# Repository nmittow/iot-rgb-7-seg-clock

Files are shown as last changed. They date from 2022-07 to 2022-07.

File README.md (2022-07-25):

# iot-rgb-7-seg-clock

RGB leds arranged to simulate the look of a 7 segment display.

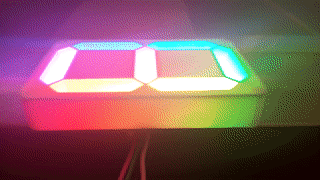
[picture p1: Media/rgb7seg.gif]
single digit rgb cycling

basic animation running on clock

Raspberry Pi &amp; ESP32 based controllers.
Raspberry Pi controller
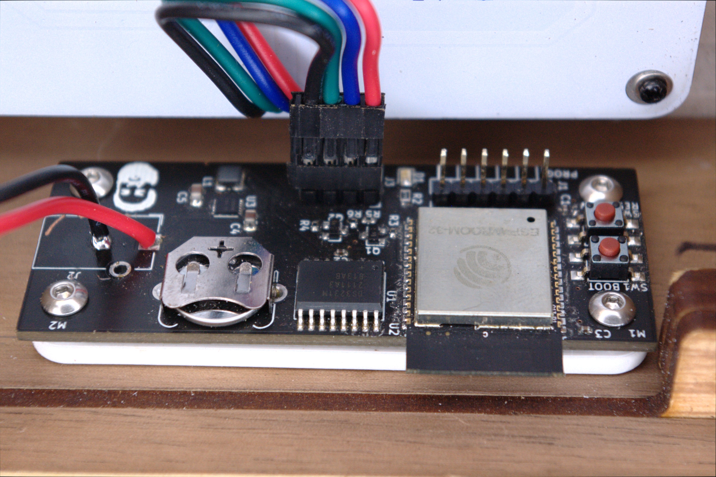
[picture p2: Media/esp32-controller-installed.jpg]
ESP32 controller


ESP32 version features: realtime clock, syncs to a network time server,  supports various time display animations.

All PCBs in KiCAD.

Raspberry Pi version features: all ESP32 features plus: 3.5mm audio jack and 5V relay controlled power output (for alarm audio), python library for controlling display &amp; alarm functionality (in-progress).

Motivation: I wanted an alarm that syncs with my various calendars (google, protonmail, etc) capable of 'smart' functionality like adjusting alarm time based on calendar events &amp; traffic conditions, etc., but wanted those calculations to happen locally (i.e. not google now/similar).  Love the look of 7 segment displays but wanted a bit more control of the display.

Construction: PCBs for controllers (ESP32 based &amp; Raspberry Pi cape), 7 segment digits are custom PCBs with APA102 addressable LEDs (3 per segment), daisy-chain-able.  3D Printed shrouds &amp; laser cut acrylic diffuser front, all in a stylish wooden box.  PCBs designed in KiCAD, 3D Modeling in AutoCAD & Fusion360.

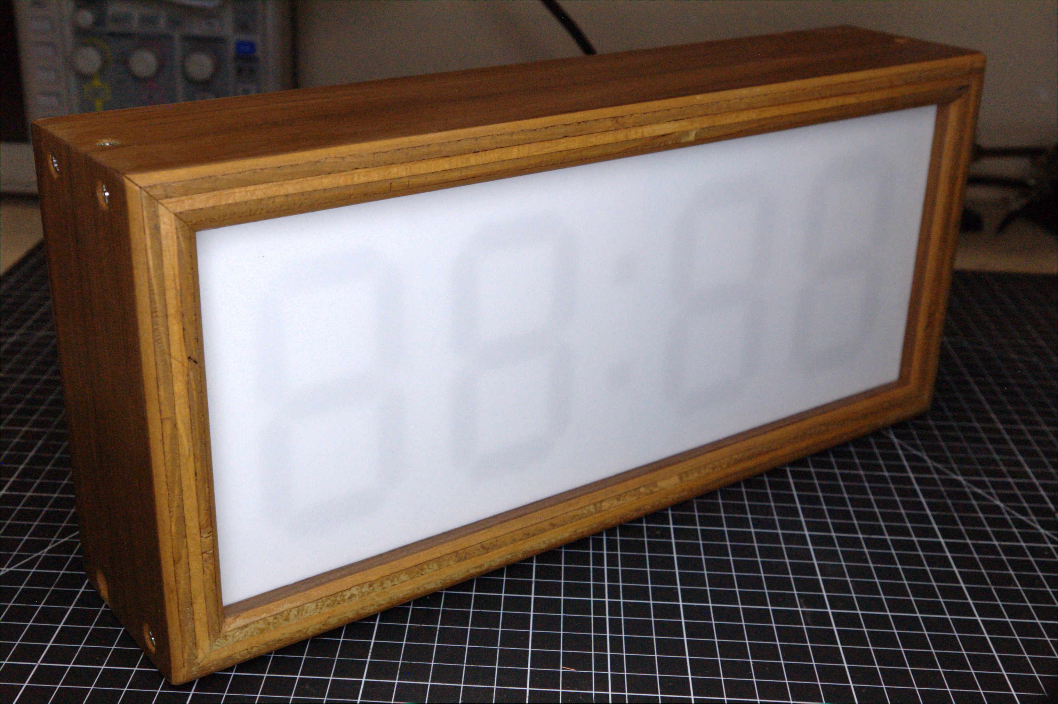
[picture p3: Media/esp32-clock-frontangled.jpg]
Front turned off

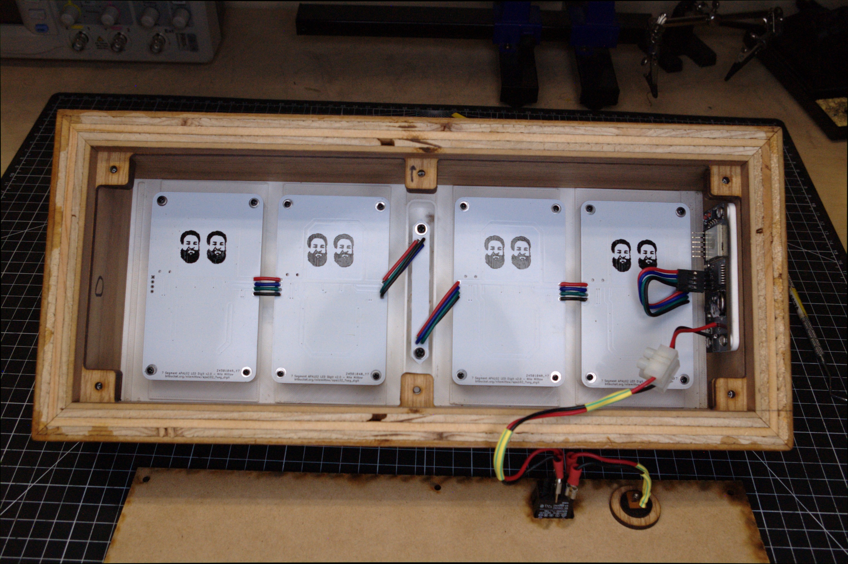
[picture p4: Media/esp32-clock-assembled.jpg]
Assembly of clock


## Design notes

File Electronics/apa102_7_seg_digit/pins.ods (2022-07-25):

hc165 | hc595 | Other | rpi gpio | Rpi Pin | Function
Qh |  |  | GPIO 9 | 21 | MISO
CLK |  |  | GPIO 11 | 23 | SCLK
CLK INH |  |  | GPIO 8 | 24 | CS0
SH/LD |  |  | GPIO 25 | 22 | en/dis loading
 | SER |  | GPIO 10 | 19 | MOSI
 | OE | GND |  |  | Output Ena
 | SRCLR | 5V |  |  | Sync. Clear
 | SRCLK |  | GPIO 7 |  | CS1

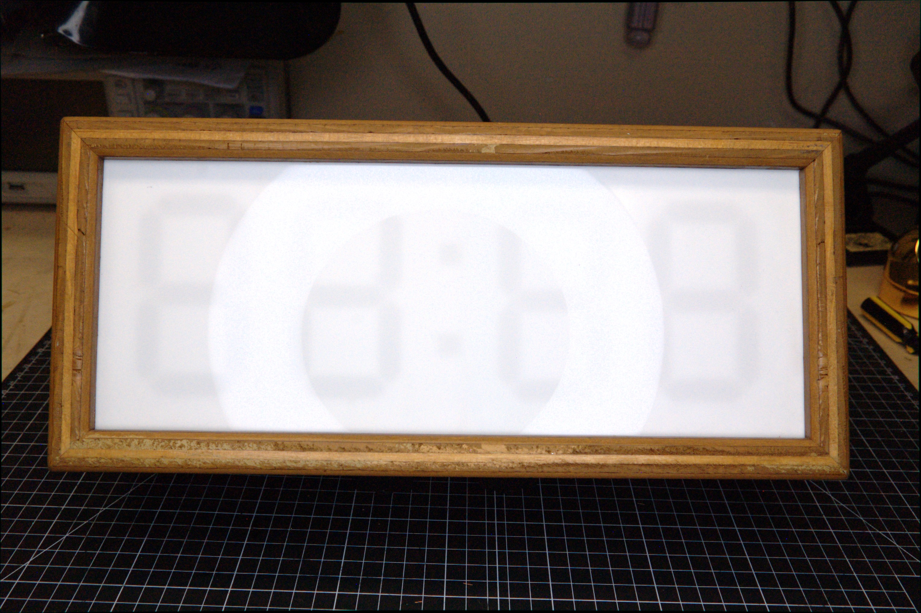
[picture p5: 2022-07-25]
Media/esp32-clock-frontflat.jpg

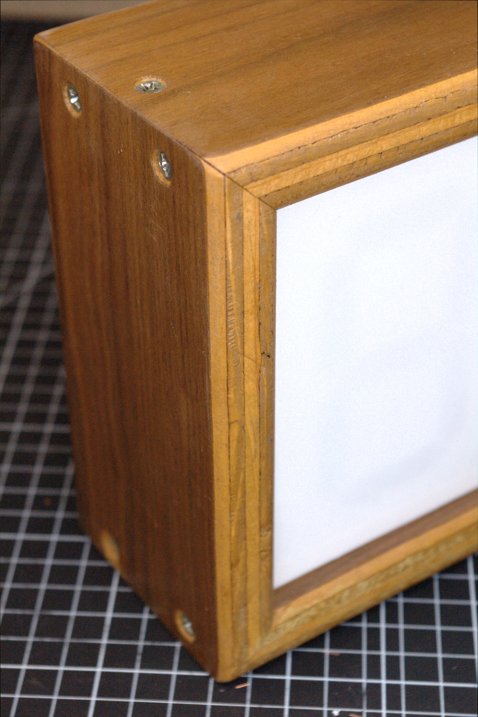
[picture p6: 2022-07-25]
Media/esp32-clock-cornercloseup.jpg

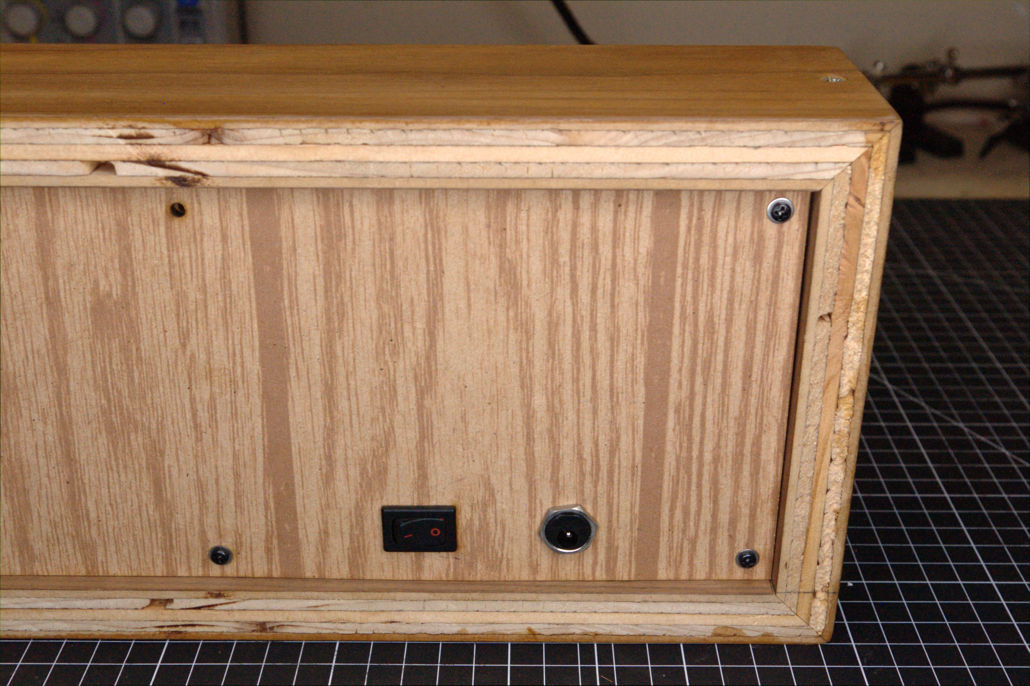
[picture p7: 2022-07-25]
Media/esp32-clock-backports.jpg

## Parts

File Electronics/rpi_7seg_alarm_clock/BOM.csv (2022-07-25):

Mouser # | Link | Mfr. # | Manufacturer | Description | RoHS | Lifecycle | Order Qty. | Price (USD) | Ext.: (USD)
655-RT314F03 | https://www.mouser.com/ProductDetail/655-RT314F03 | RT314F03 | TE Connectivity | General Purpose Relays SPDT 16A 3VDC PCB MINIATURE RELAY |  |  | 1 | $6.79 | $6.79
833-2SK3018-TP | https://www.mouser.com/ProductDetail/833-2SK3018-TP | 2SK3018-TP | Micro Commercial Components (MCC) | MOSFET N-Channel MOSFET | RoHS Compliant |  | 2 | $0.34 | $0.68
595-CD4078BPWR | https://www.mouser.com/ProductDetail/595-CD4078BPWR | CD4078BPWR | Texas Instruments | Logic Gates CMOS 8-Input NOR/OR | RoHS Compliant |  | 1 | $0.55 | $0.55
595-SN74HC08D | https://www.mouser.com/ProductDetail/595-SN74HC08D | SN74HC08D | Texas Instruments | Logic Gates Quad 2-Input | RoHS Compliant |  | 1 | $0.47 | $0.47
534-3001 | https://www.mouser.com/ProductDetail/534-3001 | 3001 | Keystone Electronics | Coin Cell Battery Holders TH COIN CELL BATTERY HOLDER 12mm | RoHS Compliant |  | 1 | $0.43 | $0.43
538-67643-2910 | https://www.mouser.com/ProductDetail/538-67643-2910 | 67643-2910 | Molex | USB Connectors USB REC 4P RA SHLD TYPE A AUFL | RoHS Compliant |  | 1 | $1.56 | $1.56
512-BSS138 | https://www.mouser.com/ProductDetail/512-BSS138 | BSS138 | ON Semiconductor | MOSFET SOT-23 N-CH LOGIC | RoHS Compliant |  | 2 | $0.26 | $0.52
771-74HC14D-T | https://www.mouser.com/ProductDetail/771-74HC14D-T | 74HC14D,653 | Nexperia | Inverters HEX INVERTER SCHMITT TRIGGER | RoHS Compliant |  | 1 | $0.46 | $0.46
700-DS3231M+ | https://www.mouser.com/ProductDetail/700-DS3231M+ | DS3231M+ | Maxim Integrated | Real Time Clock +/-5ppm, I C Real-Time Clock | RoHS Compliant |  | 1 | $7.75 | $7.75
595-SN74HC165PWR | https://www.mouser.com/ProductDetail/595-SN74HC165PWR | SN74HC165PWR | Texas Instruments | Counter Shift Registers 8-Bit Parallel-Load | RoHS Compliant |  | 1 | $0.47 | $0.47
485-4079 | https://www.mouser.com/ProductDetail/485-4079 | 4079 | Adafruit | Adafruit Accessories 2x20 Socket Riser Header for Raspberry Pi HATs and Bonnets |  | New Product | 1 | $1.95 | $1.95
603-RC0402FR-7W10KL | https://www.mouser.com/ProductDetail/603-RC0402FR-7W10KL | RC0402FR-7W10KL | Yageo | Thick Film Resistors - SMD 10K ohm 1% 50V General Purpose | RoHS Compliant By Exemption |  | 20 | $0.02 | $0.36
81-GRM155C71H104JE9D | https://www.mouser.com/ProductDetail/81-GRM155C71H104JE9D | GRM155C71H104JE19D | Murata | Multilayer Ceramic Capacitors MLCC - SMD/SMT | RoHS Compliant |  | 12 | $0.08 | $0.91

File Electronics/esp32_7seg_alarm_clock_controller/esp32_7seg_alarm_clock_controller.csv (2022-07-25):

 | Source: | /home/usb/Disks/hecate/Projects/esp32_7seg_alarm_clock_controller/esp32_7seg_alarm_clock_controller.sch
 | Date: | Sun 26 Dec 2021 02:06:49 PM PST
 | Tool: | Eeschema 5.1.12-1.fc33
 | Component Count: | 24
have? | Ref | Value | Footprint | Datasheet | Manufacturer | Vendor
yes | BT1 | CR1220 | Battery:BatteryHolder_Keystone_3001_1x12mm | ~
yes | C1 | 0.1uF | Capacitor_SMD:C_0402_1005Metric | ~
yes | C2 | 0.1uF | Capacitor_SMD:C_0402_1005Metric | ~
yes | C3 | 0.1uF | Capacitor_SMD:C_0402_1005Metric | ~
yes | C4 | CP1in 4.7uF | Capacitor_SMD:C_0805_2012Metric | ~
yes | C5 | CP1out 10uF | Capacitor_SMD:C_0805_2012Metric | ~
yes | D1 | SLED | LED_SMD:LED_0805_2012Metric | ~
 | J1 | PROG | Connector_PinHeader_2.54mm:PinHeader_1x06_P2.54mm_Horizontal | ~
yes | J2 | 5V_IN | Connector_BarrelJack:BarrelJack_CUI_PJ-102AH_Horizontal | ~
 | J3 | DISP | Connector_PinSocket_2.54mm:PinSocket_1x04_P2.54mm_Horizontal | ~
yes | L1 | LP1 4.7uH | Inductor_SMD:L_Wuerth_MAPI-3015 | ~
 | Q1 | BSS138 | Package_TO_SOT_SMD:SOT-23 | https://www.onsemi.com/pub/Collateral/BSS138-D.PDF
 | Q2 | BSS138 | Package_TO_SOT_SMD:SOT-23 | https://www.onsemi.com/pub/Collateral/BSS138-D.PDF
yes | R1 | 10K | Resistor_SMD:R_0402_1005Metric | ~
yes | R2 | RSLED_60 | Resistor_SMD:R_0603_1608Metric | ~
yes | R3 | 10K | Resistor_SMD:R_0402_1005Metric | ~
yes | R4 | 10K | Resistor_SMD:R_0402_1005Metric | ~
yes | R5 | 10K | Resistor_SMD:R_0402_1005Metric | ~
yes | R6 | 10K | Resistor_SMD:R_0402_1005Metric | ~
yes | SW1 | BOOT | Button_Switch_SMD:SW_SPST_TL3305A | ~
yes | SW2 | RESET_SW | Button_Switch_SMD:SW_SPST_TL3305A | ~
yes | U1 | DS3231M | Package_SO:SOIC-16W_7.5x10.3mm_P1.27mm | http://datasheets.maximintegrated.com/en/ds/DS3231.pdf
yes | U2 | ESP32-WROOM-32 | RF_Module:ESP32-WROOM-32 | https://www.espressif.com/sites/default/files/documentation/esp32-wroom-32_datasheet_en.pdf
yes | U3 | PAM2306AYPKE | Package_DFN_QFN:WDFN-12-1EP_3x3mm_P0.45mm_EP1.7x2.5mm | https://www.diodes.com/assets/Datasheets/PAM2306.pdf

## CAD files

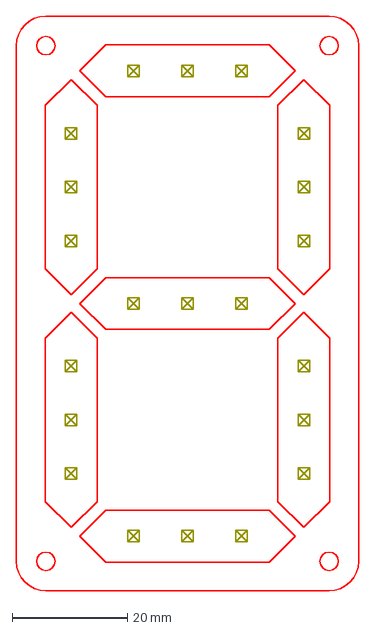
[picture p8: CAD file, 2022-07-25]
Electronics/apa102_7_seg_digit/APA102-7Seg-PCB-Template-forkicad.dxf
59.3 x 99.6 mm

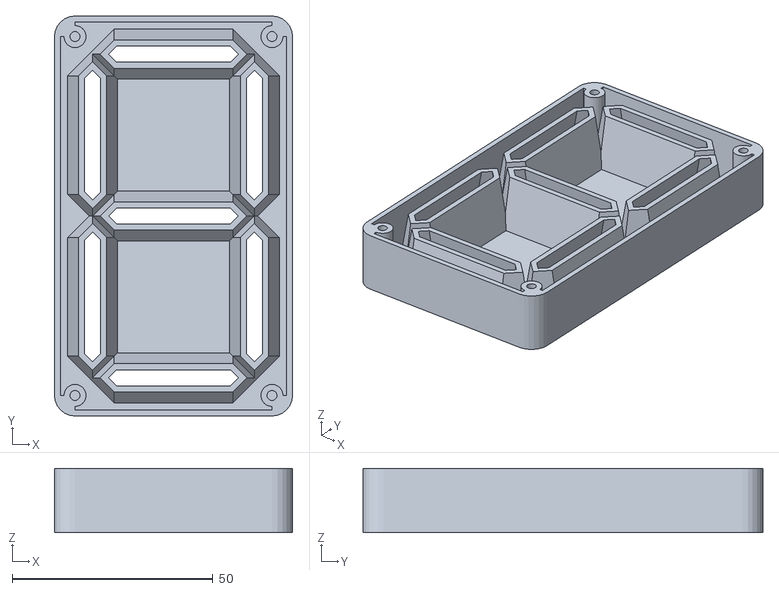
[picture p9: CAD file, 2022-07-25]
Mechanical/APA102-7Seg-PCB-Shroud.stl
59.3 x 99.6 x 16.0

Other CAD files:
Electronics/apa102_7_seg_digit/APA102-7Seg-PCB-Template.dwg
Mechanical/APA102-7Seg-PCB-Template.dwg
Electronics/apa102_7_seg_digit/APA102-7Seg-PCB-Template-forkicad.dwg
Mechanical/APA102-7Seg-PCB-Shroud.dwg
Mechanical/APA102-7Seg-PCB-Template-forkicad.dwg

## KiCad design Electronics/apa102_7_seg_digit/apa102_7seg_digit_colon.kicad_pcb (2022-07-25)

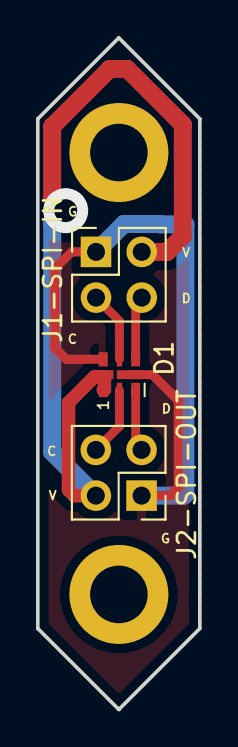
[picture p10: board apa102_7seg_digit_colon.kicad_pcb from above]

Board: 2 copper layers, 9.0 x 37.3 mm, 3 parts (0 on the bottom side), 6 nets.

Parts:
D1: A_0; LED-APA102-2020
J1-SPI-IN: SPI_IN; PinHeader_2x02_P2.54mm_Vertical
J2-SPI-OUT: SPI_OUT; PinHeader_2x02_P2.54mm_Vertical

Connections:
+5V: D1.1, J1-SPI-IN.2, J2-SPI-OUT.2
GND: D1.6, J1-SPI-IN.1, J2-SPI-OUT.1
unnamed: D1.2, J2-SPI-OUT.4
unnamed: D1.3, J2-SPI-OUT.3
unnamed: D1.4, J1-SPI-IN.4
unnamed: D1.5, J1-SPI-IN.3

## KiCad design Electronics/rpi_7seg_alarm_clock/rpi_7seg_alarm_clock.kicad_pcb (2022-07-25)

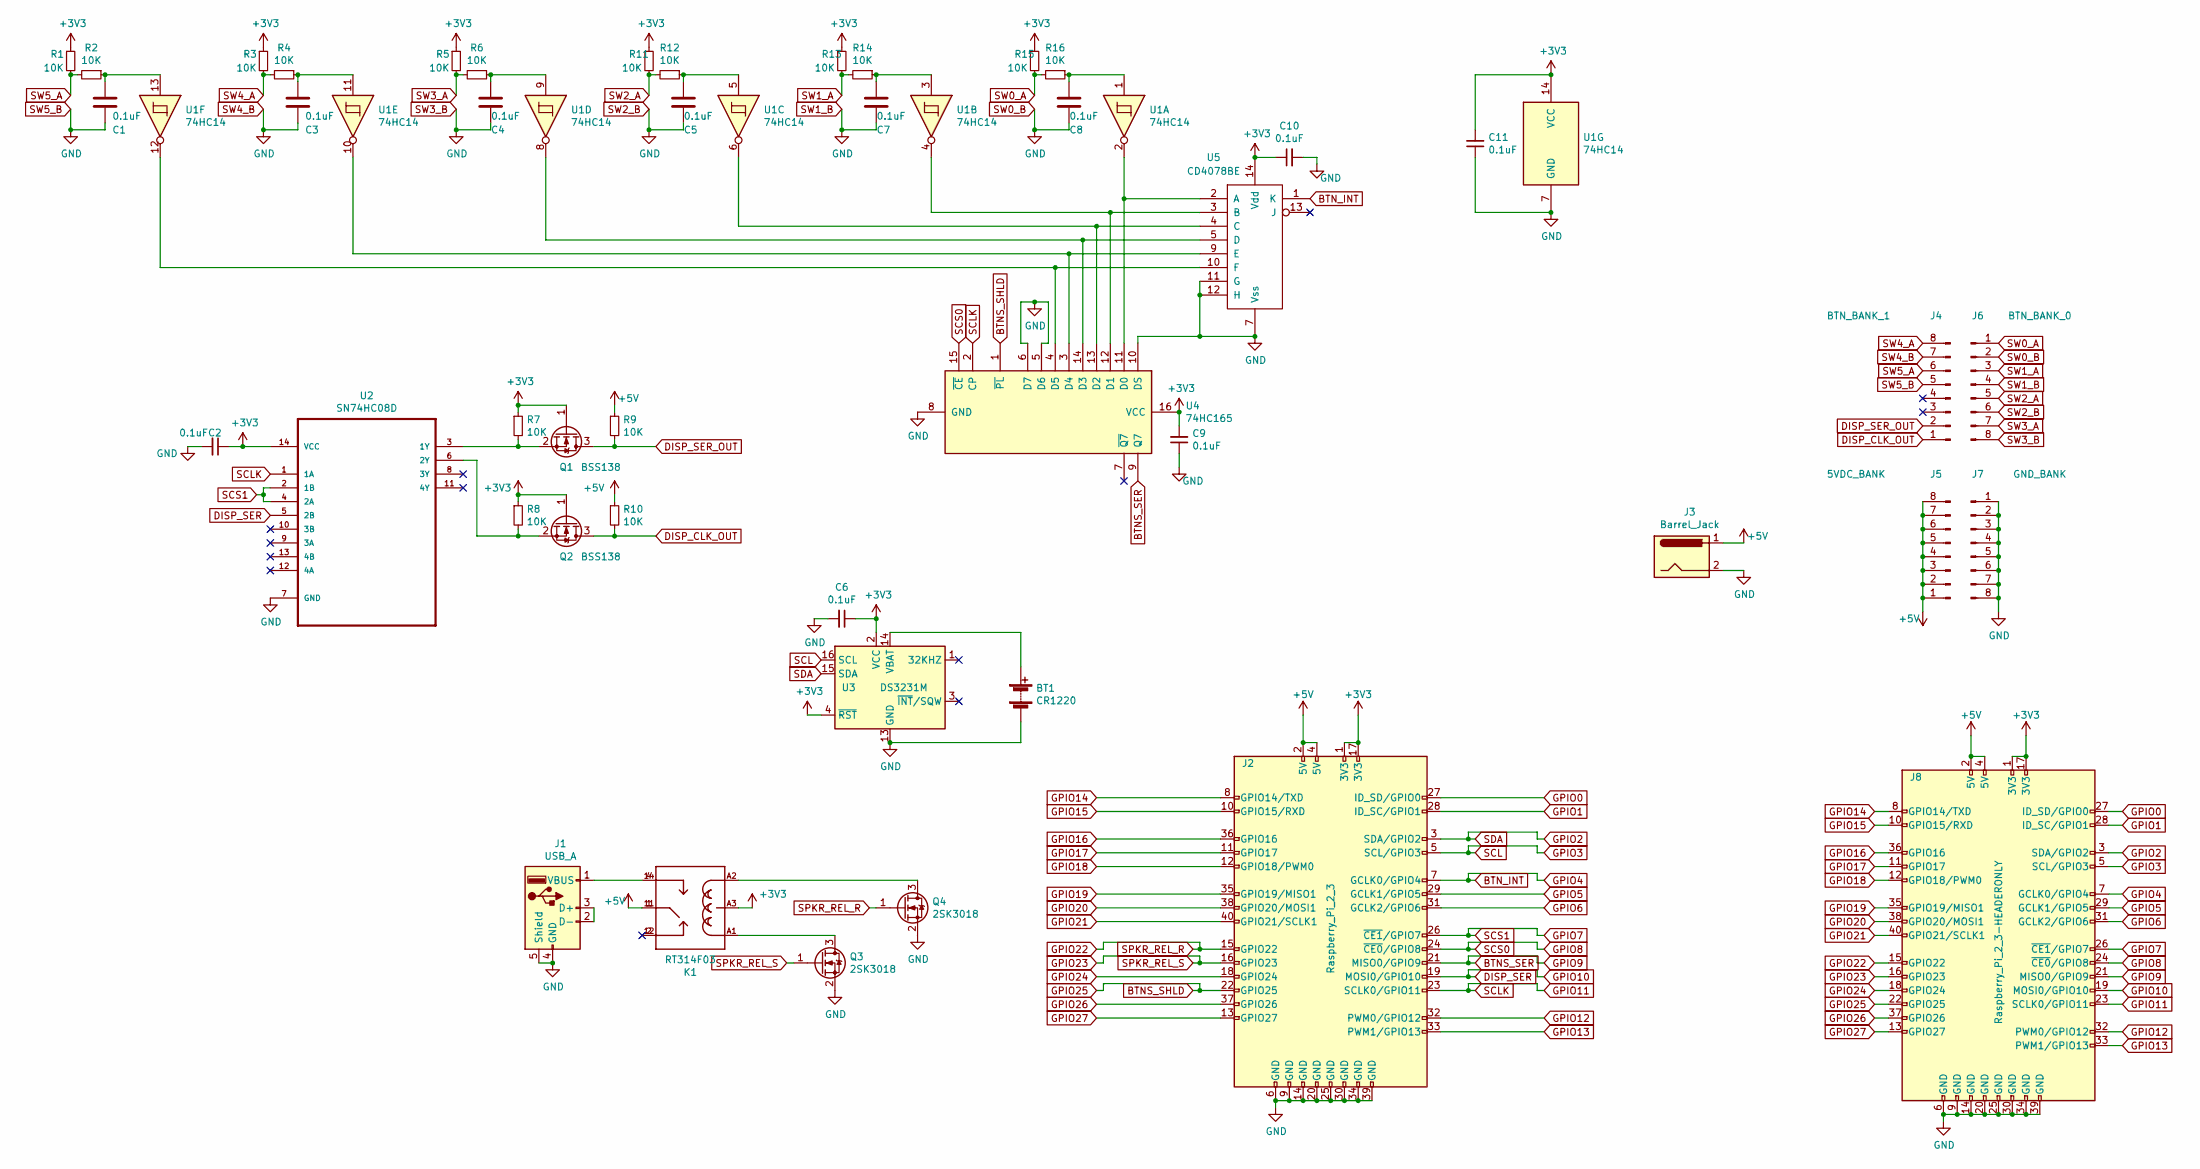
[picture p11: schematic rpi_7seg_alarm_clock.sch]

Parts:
BT1: CR1220; BatteryHolder_Keystone_3001_1x12mm
C1, C2, C3, C4, C5, C6, C7, C8, C9, C10, C11: 0.1uF; C_0805_2012Metric
J1: USB_A; USB_A_Molex_67643_Horizontal
J2: Raspberry_Pi_2_3; PinHeader_2x20_P2.54mm_Vertical
J3: Barrel_Jack; PinHeader_1x02_P2.54mm_Vertical
J4: BTN_BANK_1; TerminalBlock_Phoenix_PT-1,5-8-3.5-H_1x08_P3.50mm_Horizontal
J5: 5VDC_BANK; TerminalBlock_Phoenix_PT-1,5-8-3.5-H_1x08_P3.50mm_Horizontal
J6: BTN_BANK_0; TerminalBlock_Phoenix_PT-1,5-8-3.5-H_1x08_P3.50mm_Horizontal
J7: GND_BANK; TerminalBlock_Phoenix_PT-1,5-8-3.5-H_1x08_P3.50mm_Horizontal
J8: Raspberry_Pi_2_3-HEADERONLY; PinHeader_2x20_P2.54mm_Vertical
K1: RT314F03; RELAY_RT314F03
Q1, Q2: BSS138; SOT-23
Q3, Q4: 2SK3018; SOT-323_SC-70
R1, R2, R3, R4, R5, R6, R7, R8, R9, R10, R11, R12, R13, R14, R15, R16: 10K; R_0805_2012Metric
U1: 74HC14; SOIC-14_3.9x8.7mm_P1.27mm
U2: SN74HC08D; SOIC127P600X175-14N
U3: DS3231M; SOIC-16W_7.5x10.3mm_P1.27mm
U4: 74HC165; TSSOP-16_4.4x5mm_P0.65mm
U5: CD4078BE; TSSOP-14_4.4x5mm_P0.65mm

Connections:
+3V3: C2.1, C6.1, C9.2, C10.1, C11.2, J2.1 (3V3), J2.17 (3V3), J8.1 (3V3), J8.17 (3V3), K1.A3, Q1.1 (G), Q2.1 (G), R1.1, R3.1, R5.1, R7.1, R8.1, R11.1, R13.1, R15.1, U1.14 (VCC), U2.14 (VCC), U3.2 (VCC), U3.4 (~RST), U4.16 (VCC), U5.14 (Vdd)
+5V: J2.2 (5V), J2.4 (5V), J3.1, J5.1, J5.2, J5.3, J5.4, J5.5, J5.6, J5.7, J5.8, J8.2 (5V), J8.4 (5V), K1.1, K1.11, R9.1, R10.1
BTNS_SER: J2.21 (MISO0/GPIO9), J8.21 (MISO0/GPIO9), U4.9 (Q7)
BTNS_SHLD: J2.22 (GPIO25), J8.22 (GPIO25), U4.1 (~PL)
BTN_INT: J2.7 (GCLK0/GPIO4), J8.7 (GCLK0/GPIO4), U5.1 (K)
DISP_CLK_OUT: J4.1, Q2.3 (D), R10.2
DISP_SER: J2.19 (MOSI0/GPIO10), J8.19 (MOSI0/GPIO10), U2.5 (2B)
DISP_SER_OUT: J4.2, Q1.3 (D), R9.2
GPIO0: J2.27 (ID_SD/GPIO0), J8.27 (ID_SD/GPIO0)
GPIO1: J2.28 (ID_SC/GPIO1), J8.28 (ID_SC/GPIO1)
GPIO2: J2.3 (SDA/GPIO2), J8.3 (SDA/GPIO2), U3.15 (SDA)
GPIO3: J2.5 (SCL/GPIO3), J8.5 (SCL/GPIO3), U3.16 (SCL)
GPIO5: J2.29 (GCLK1/GPIO5), J8.29 (GCLK1/GPIO5)
GPIO6: J2.31 (GCLK2/GPIO6), J8.31 (GCLK2/GPIO6)
GPIO7: J2.26 (~CE1~/GPIO7), J8.26 (~CE1~/GPIO7), U2.2 (1B), U2.4 (2A)
GPIO8: J2.24 (~CE0~/GPIO8), J8.24 (~CE0~/GPIO8), U4.15 (~CE)
GPIO11: J2.23 (SCLK0/GPIO11), J8.23 (SCLK0/GPIO11), U2.1 (1A), U4.2 (CP)
GPIO12: J2.32 (PWM0/GPIO12), J8.32 (PWM0/GPIO12)
GPIO13: J2.33 (PWM1/GPIO13), J8.33 (PWM1/GPIO13)
GPIO14: J2.8 (GPIO14/TXD), J8.8 (GPIO14/TXD)
GPIO15: J2.10 (GPIO15/RXD), J8.10 (GPIO15/RXD)
GPIO16: J2.36 (GPIO16), J8.36 (GPIO16)
GPIO17: J2.11 (GPIO17), J8.11 (GPIO17)
GPIO18: J2.12 (GPIO18/PWM0), J8.12 (GPIO18/PWM0)
GPIO19: J2.35 (GPIO19/MISO1), J8.35 (GPIO19/MISO1)
GPIO20: J2.38 (GPIO20/MOSI1), J8.38 (GPIO20/MOSI1)
GPIO21: J2.40 (GPIO21/SCLK1), J8.40 (GPIO21/SCLK1)
GPIO22: J2.15 (GPIO22), J8.15 (GPIO22), Q4.1 (G)
GPIO23: J2.16 (GPIO23), J8.16 (GPIO23), Q3.1 (G)
GPIO24: J2.18 (GPIO24), J8.18 (GPIO24)
GPIO26: J2.37 (GPIO26), J8.37 (GPIO26)
GPIO27: J2.13 (GPIO27), J8.13 (GPIO27)
unnamed: BT1.1 (+), U3.14 (VBAT)
unnamed: C1.1, R2.1, U1.13
unnamed: C3.1, R4.1, U1.11
unnamed: C4.1, R6.1, U1.9
unnamed: C5.1, R12.1, U1.5
unnamed: C7.1, R14.1, U1.3
unnamed: C8.1, R16.1, U1.1
unnamed: J1.1 (VBUS), K1.4, K1.14
unnamed: J1.2 (D-), J1.3 (D+)
unnamed: K1.2, K1.12
unnamed: K1.A1, Q3.3 (D)
unnamed: K1.A2, Q4.3 (D)
unnamed: Q1.2 (S), R7.2, U2.3 (1Y)
unnamed: Q2.2 (S), R8.2, U2.6 (2Y)
unnamed: U1.2, U4.11 (D0), U5.2 (A)
unnamed: U1.4, U4.12 (D1), U5.3 (B)
unnamed: U1.6, U4.13 (D2), U5.4 (C)
unnamed: U1.8, U4.14 (D3), U5.5 (D)
unnamed: U1.10, U4.3 (D4), U5.9 (E)
unnamed: U1.12, U4.4 (D5), U5.10 (F)
SW0_A: J6.1, R15.2, R16.2
SW0_B: BT1.2 (-), C1.2, C2.2, C3.2, C4.2, C5.2, C6.2, C7.2, C8.2, C9.1, C10.2, C11.1, J1.4 (GND), J1.5 (Shield), J2.6 (GND), J2.9 (GND), J2.14 (GND), J2.20 (GND), J2.25 (GND), J2.30 (GND), J2.34 (GND), J2.39 (GND), J3.2, J4.5, J4.7, J6.2, J6.4, J6.6, J6.8, J7.1, J7.2, J7.3, J7.4, J7.5, J7.6, J7.7, J7.8, J8.6 (GND), J8.9 (GND), J8.14 (GND), J8.20 (GND), J8.25 (GND), J8.30 (GND), J8.34 (GND), J8.39 (GND), Q3.2 (S), Q4.2 (S), U1.7 (GND), U2.7 (GND), U3.5 (GND), U3.6 (GND), U3.7 (GND), U3.8 (GND), U3.9 (GND), U3.10 (GND), U3.11 (GND), U3.12 (GND), U3.13 (GND), U4.5 (D6), U4.6 (D7), U4.8 (GND), U4.10 (DS), U5.7 (Vss), U5.11 (G), U5.12 (H)
SW1_A: J6.3, R13.2, R14.2
SW2_A: J6.5, R11.2, R12.2
SW3_A: J6.7, R5.2, R6.2
SW4_A: J4.8, R3.2, R4.2
SW5_A: J4.6, R1.2, R2.2

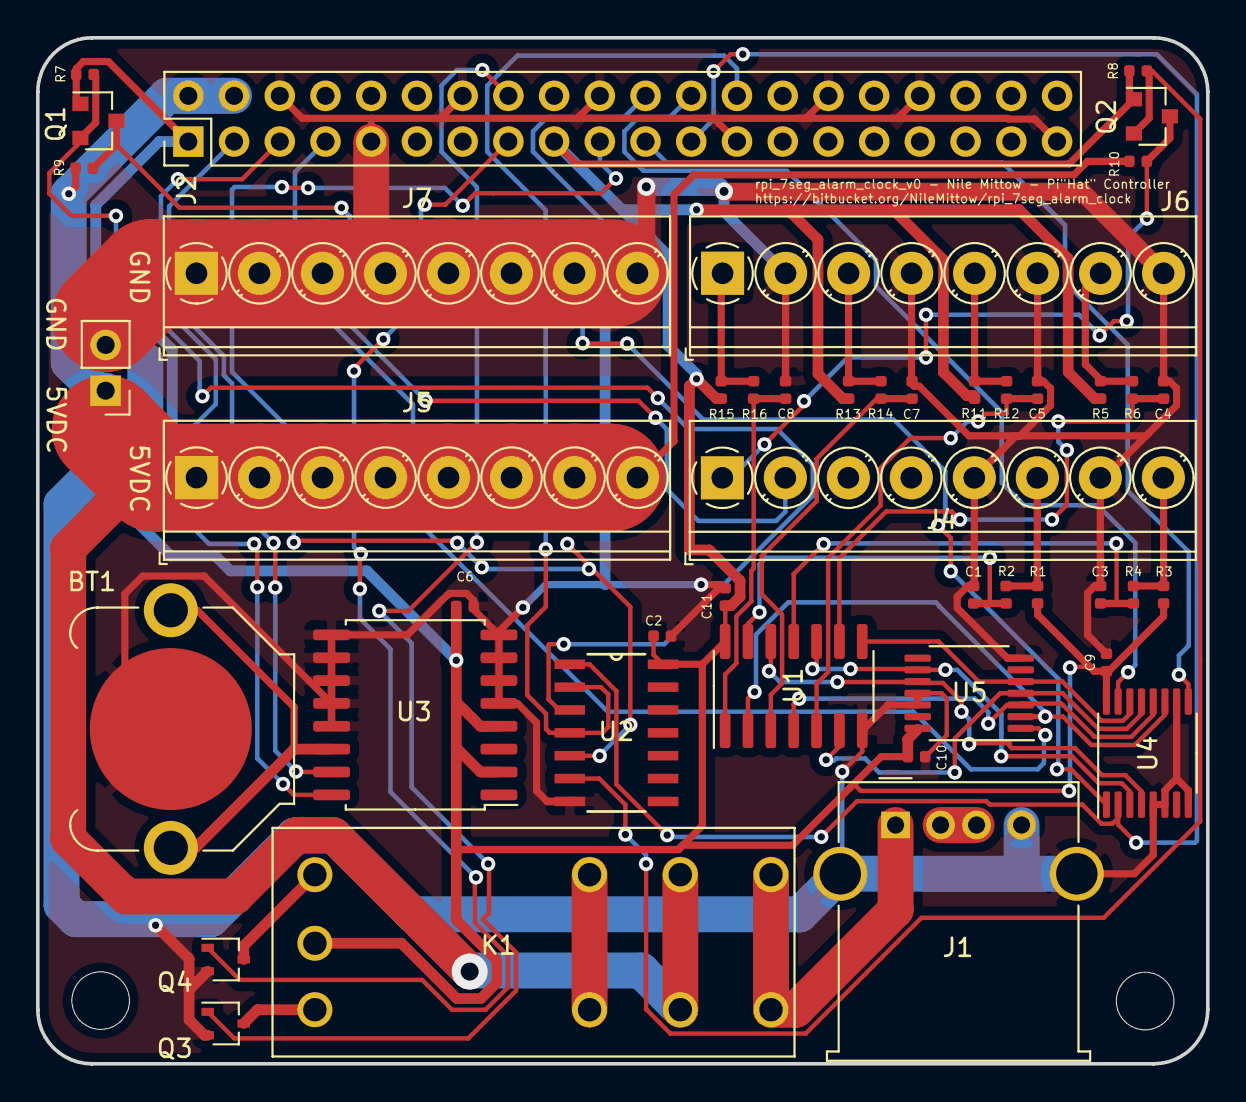
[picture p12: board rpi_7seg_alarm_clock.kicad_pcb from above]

Board: 2 copper layers, 65.0 x 57.0 mm, 46 parts (1 on the bottom side), 42 nets.

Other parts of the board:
nilesface: nilesface_small

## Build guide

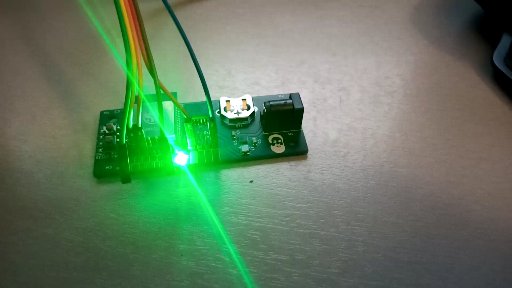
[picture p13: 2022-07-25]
Media/esp32-controller-assembled-1.jpg

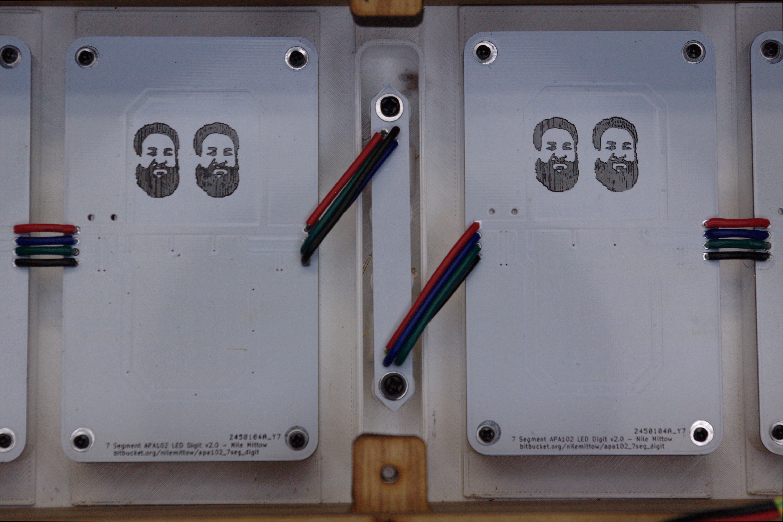
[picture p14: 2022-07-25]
Media/esp32-clock-assembled-middledigitscloseup.jpg

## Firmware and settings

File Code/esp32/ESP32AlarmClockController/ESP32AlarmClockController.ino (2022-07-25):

/***

Board: ESP32 Dev Module
Speed: 921600
Flash Freq: 80MHz
Core Debug: None
Port: /dev/ttyUSB0

Wiring:

 0 : X
 1 : Yellow
 2 : Orange
 3 : X
 4 : X
 5 : X

 0 : Red
 1 : X
 2 : X
 3 : Black


GREEN
YELLOW
ORANGE
RED
BROWN


**/
#include <SPI.h>
#include <Wire.h>;
#include <RTClib.h>
#include <WiFi.h>
#include "time.h"
#include <ESPmDNS.h>
#include <WiFiUdp.h>
#include <ArduinoOTA.h>

#define FASTLED_ALL_PINS_HARDWARE_SPI
#include <FastLED.h>
#define NUMPIXELS 86
#define DATA_PIN  23
#define CLOCK_PIN 18

#include "APA1027SEG_digitMasks.h"

#define STATUS_LED 2
#define OTA_PORT 3232
#define HOSTNAME "esp32-clock"
#define OTA_HOSTNAME "esp32-clock-upload"

#define TEST_ONCOLOR  CRGB::White
#define TEST_OFFCOLOR CRGB::Red

#define AMPM false

const char* ssid       = "SSID";
const char* password   = "PASSWORD";

const char* ntpServer          = "time.cloudflare.com";
const long  gmtOffset_sec      = -8 * 3600;
const int   daylightOffset_sec = -7 * 3600;
const int32_t wifiTimeout    = 10 * 60;
const int32_t NTPSyncInterval   =  5 * 60;
RTC_DS3231 rtc;

unsigned syncState = 0;
bool ledState = false;
bool colonState = false;
DateTime lastWifiConn(uint32_t(0));
DateTime lastNTPSync(uint32_t(0));

CRGB leds[NUMPIXELS];
CRGB displayMask[NUMPIXELS];

unsigned dcount = 0;
int whiteLed = 0;

bool nonce = true;

char daysOfTheWeek[7][12] = {"Sunday", "Monday", "Tuesday", "Wednesday", "Thursday", "Friday", "Saturday"};

void setup () {
  #ifndef ESP8266
    while (!Serial); // for Leonardo/Micro/Zero
  #endif
  Serial.begin(9600);
  delay(3000); // wait for console opening
  if (! rtc.begin()) {
    Serial.println("Couldn't find RTC");
    while (1); //??
  }
  pinMode(STATUS_LED,OUTPUT);
  Serial.printf("Connecting to %s ", ssid);
  WiFi.mode(WIFI_STA);
  WiFi.config(INADDR_NONE, INADDR_NONE, INADDR_NONE, INADDR_NONE);
  WiFi.setHostname(HOSTNAME);
  WiFi.begin(ssid, password);
  configTime(gmtOffset_sec, daylightOffset_sec, ntpServer);
  lastWifiConn = rtc.now();
  FastLED.addLeds<APA102, DATA_PIN, CLOCK_PIN, RGB, DATA_RATE_MHZ(4)>(leds, NUMPIXELS);  // BGR ordering is typical
  
}

void loop () {
  ArduinoOTA.handle();
  syncState = sync(syncState);
  DateTime now = rtc.now();
  if (whiteLed%8 == 0 ) {
    printDateTime(&now);
    digitalWrite(STATUS_LED,ledState = !ledState);
  }
  if (whiteLed < NUMPIXELS) {
    //leds[whiteLed] = TEST_ONCOLOR;
    //void applyDigitMask(CRGB* target, uint8_t digitIndex, uint8_t digit)
    //applyDigitMask(leds, 0,0);
    //applyDigitMask(leds, 1,1);
    //applyDigitMask(leds, 2,2);
    //applyDigitMask(leds, 3,3);
    //applyColonMask(leds, true);
    applyTimeMask(leds, &now, AMPM);
    leds[whiteLed] = TEST_ONCOLOR;
    FastLED.show();
    delay(10);
    leds[whiteLed] = TEST_OFFCOLOR;
    whiteLed++;
  }
  else whiteLed = 0;
}

unsigned sync(unsigned state) {
  switch(state){
    case 0: {
      TimeSpan uconTime = rtc.now() - lastWifiConn;
      if (WiFi.status() == WL_CONNECTED) {
        Serial.print("CONNECTED: IP address: ");
        Serial.println(WiFi.localIP());
        state++;
        lastWifiConn = rtc.now();
        if (nonce) {
          nonce = false;
          launchOTADaemon();
        }
      }
      else if (uconTime.totalseconds() > wifiTimeout){
        Serial.println("WIFI TIMOUT TRIGGERED");
        WiFi.disconnect();
        WiFi.reconnect();
        lastWifiConn = rtc.now();
      }
      break;
    }
    case 1: {
      
      TimeSpan syncTime = rtc.now() - lastNTPSync;
      //Serial.print("TIME SINCE LAST SYNC: ");
      //Serial.println(syncTime.totalseconds());
      if (syncTime.totalseconds() > NTPSyncInterval) {
        if (syncNTPTime() < 0) {
          Serial.println("NTP GET FAILURE");
        }
        else {
          Serial.println("NTP GET SUCCESS");
          lastNTPSync = rtc.now();
          lastWifiConn = rtc.now();
          state--;
        }
      }
      else {
        if (WiFi.status() == WL_CONNECTED) {
          lastWifiConn = rtc.now();
        }
      }
      break;
    }
  }
  return state;
}

void printDateTime(DateTime *dt) {
  Serial.print(dt->year(), DEC);
  Serial.print('/');
  Serial.print(dt->month(), DEC);
  Serial.print('/');
  Serial.print(dt->day(), DEC);
  Serial.print(" (");
  Serial.print(daysOfTheWeek[dt->dayOfTheWeek()]);
  Serial.print(") ");
  Serial.print(dt->hour(), DEC);
  Serial.print(':');
  Serial.print(dt->minute(), DEC);
  Serial.print(':');
  Serial.print(dt->second(), DEC);
  Serial.println();
  return;
}

int syncNTPTime() {
  struct tm timeinfo;
  if(!getLocalTime(&timeinfo)){
    return -1;
  }
  else {
    rtc.adjust(DateTime(timeinfo.tm_year+1900, timeinfo.tm_mon+1, timeinfo.tm_mday, timeinfo.tm_hour, timeinfo.tm_min, timeinfo.tm_sec));
    return 0;
  }
}

int launchOTADaemon(){
  ArduinoOTA.setPort(OTA_PORT);
  ArduinoOTA.setHostname(OTA_HOSTNAME);
  ArduinoOTA
    .onStart([]() {
      String type;
      if (ArduinoOTA.getCommand() == U_FLASH)
        type = "sketch";
      else // U_SPIFFS
        type = "filesystem";

      // NOTE: if updating SPIFFS this would be the place to unmount SPIFFS using SPIFFS.end()
      Serial.println("Start updating " + type);
    })
    .onEnd([]() {
      Serial.println("\nEnd");
    })
    .onProgress([](unsigned int progress, unsigned int total) {
      Serial.printf("Progress: %u%%\r", (progress / (total / 100)));
    })
    .onError([](ota_error_t error) {
      Serial.printf("Error[%u]: ", error);
      if (error == OTA_AUTH_ERROR) Serial.println("Auth Failed");
      else if (error == OTA_BEGIN_ERROR) Serial.println("Begin Failed");
      else if (error == OTA_CONNECT_ERROR) Serial.println("Connect Failed");
      else if (error == OTA_RECEIVE_ERROR) Serial.println("Receive Failed");
      else if (error == OTA_END_ERROR) Serial.println("End Failed");
    });

  ArduinoOTA.begin();
}

void applyDigitMask(CRGB* target, uint8_t digitIndex, uint8_t digit) {
  uint8_t offset = 21 * digitIndex;
  if (digitIndex > 1) offset += 2;
  for (uint8_t i=0; i<21; i++) {
    target[i+offset] -= digitMasks[digit][i];
  }
  return;
}

void applyColonMask(CRGB* target, bool state) {
  target[42] -= (state?(CRGB::Black,CRGB::Black,CRGB::Black):(CRGB::White,CRGB::White,CRGB::White));
  target[43] -= (state?(CRGB::Black,CRGB::Black,CRGB::Black):(CRGB::White,CRGB::White,CRGB::White));
  return;
}

void applyTimeMask(CRGB* target, DateTime *dt, bool ampm) {
  uint8_t hr = ampm?dt->hour()%12:dt->hour(); 
  if (hr < 10) {
    applyDigitMask(target, 0,0);
    applyDigitMask(target, 1,hr);
  }
  else if (hr > 19) {
    applyDigitMask(target, 0,2);
    applyDigitMask(target, 1,hr-20);
  }
  else {
    applyDigitMask(target, 0,1);
    applyDigitMask(target, 1,hr-10);
  }
  applyDigitMask(target, 2,(uint8_t)dt->minute()/10);
  applyDigitMask(target, 3,dt->minute()%10);
  applyColonMask(target, true);
  return;
}

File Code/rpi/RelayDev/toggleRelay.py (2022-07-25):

import pigpio
from signal import pause
from time import sleep

usleep = lambda x: sleep(x/1000000.0)

S = 23
R = 22

pi = pigpio.pi()
pi.set_mode(S, pigpio.OUTPUT)
pi.set_mode(R, pigpio.OUTPUT)

pi.write(S,0)
pi.write(R,0)


while True:
    pi.write(S, 1)
    sleep(1)
    pi.write(S, 0)
    sleep(2)
    pi.write(R, 1)
    sleep(1)
    pi.write(R, 0)
    sleep(2)

        

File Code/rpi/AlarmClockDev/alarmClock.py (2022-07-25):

# alarmClock.py
#
# Raspberry pi based alarm clock using APA102 LEDs
#
####################################################
from enum import Enum
import re
timeFormat = re.compile('^( ?[0-1]?[0-9]|2[0-3]):[0-5][0-9]$')

###############################################################################
# apa102pixel:
# -----------
# A single apa102 IC
#
###############################################################################
class apa102pixel:
    """Represents a single apa102 pixel"""

    colors={#Saturation   ######### 5 #########     ######### 4 #########     ######### 3 #########     ######### 2 #########     ######### 1 #########     ######### 0 #########
        "red"         :[{"r":255,"g":0  ,"b":0  },{"r":255,"g":100,"b":100},{"r":255,"g":150,"b":150},{"r":255,"g":200,"b":200},{"r":255,"g":230,"b":230},{"r":255,"g":255,"b":255}],
        "burntorange" :[{"r":255,"g":100,"b":0  },{"r":255,"g":110,"b": 20},{"r":255,"g":120,"b":100},{"r":255,"g":165,"b":155},{"r":255,"g":230,"b":210},{"r":255,"g":255,"b":255}],
        "orange"      :[{"r":255,"g":150,"b":0  },{"r":255,"g":140,"b": 20},{"r":255,"g":180,"b": 40},{"r":255,"g":220,"b":120},{"r":255,"g":240,"b":190},{"r":255,"g":255,"b":255}],
        "gold"        :[{"r":255,"g":200,"b":0  },{"r":255,"g":210,"b":  0},{"r":255,"g":230,"b":100},{"r":255,"g":240,"b":150},{"r":255,"g":255,"b":200},{"r":255,"g":255,"b":255}],
        "yellow"      :[{"r":255,"g":255,"b":0  },{"r":255,"g":255,"b": 20},{"r":255,"g":255,"b": 80},{"r":255,"g":255,"b":150},{"r":255,"g":255,"b":210},{"r":255,"g":255,"b":255}],
        "lemonlime"   :[{"r":200,"g":255,"b":0  },{"r":200,"g":255,"b": 20},{"r":220,"g":255,"b": 80},{"r":230,"g":255,"b":150},{"r":235,"g":255,"b":180},{"r":255,"g":255,"b":255}],
        "chartreuse"  :[{"r":150,"g":255,"b":0  },{"r":150,"g":255,"b": 20},{"r":200,"g":255,"b": 40},{"r":220,"g":255,"b":150},{"r":230,"g":255,"b":170},{"r":255,"g":255,"b":255}],
        "lime"        :[{"r":100,"g":255,"b":0  },{"r":110,"g":255,"b": 20},{"r":150,"g":255,"b": 40},{"r":200,"g":255,"b":150},{"r":230,"g":255,"b":160},{"r":255,"g":255,"b":255}],
        "green"       :[{"r":0  ,"g":255,"b":0  },{"r":100,"g":255,"b":100},{"r":150,"g":255,"b":250},{"r":200,"g":255,"b":200},{"r":225,"g":255,"b":225},{"r":255,"g":255,"b":255}],
        "caribbean"   :[{"r":0  ,"g":255,"b":100},{"r": 20,"g":255,"b":150},{"r":100,"g":255,"b":180},{"r":180,"g":255,"b":210},{"r":235,"g":255,"b":220},{"r":255,"g":255,"b":255}],
        "aquamarine"  :[{"r":0  ,"g":255,"b":150},{"r": 20,"g":255,"b":160},{"r":100,"g":255,"b":200},{"r":160,"g":255,"b":210},{"r":200,"g":255,"b":220},{"r":255,"g":255,"b":255}],
        "seafoam"     :[{"r":0  ,"g":255,"b":200},{"r": 20,"g":255,"b":200},{"r": 40,"g":255,"b":220},{"r":140,"g":255,"b":230},{"r":200,"g":255,"b":255},{"r":255,"g":255,"b":255}],
        "cyan"        :[{"r":0  ,"g":255,"b":255},{"r": 20,"g":255,"b":255},{"r": 40,"g":255,"b":255},{"r":150,"g":255,"b":255},{"r":180,"g":255,"b":255},{"r":255,"g":255,"b":255}],
        "teal"        :[{"r":0  ,"g":200,"b":255},{"r": 20,"g":210,"b":255},{"r": 40,"g":230,"b":255},{"r": 60,"g":240,"b":255},{"r":170,"g":255,"b":255},{"r":255,"g":255,"b":255}],
        "azure"       :[{"r":0  ,"g":150,"b":255},{"r": 20,"g":180,"b":255},{"r": 40,"g":200,"b":255},{"r": 60,"g":230,"b":255},{"r":150,"g":255,"b":255},{"r":255,"g":255,"b":255}],
        "bayern"      :[{"r":0  ,"g":100,"b":255},{"r": 20,"g":150,"b":255},{"r": 40,"g":180,"b":255},{"r": 60,"g":200,"b":255},{"r":140,"g":255,"b":255},{"r":255,"g":255,"b":255}],
        "blue"        :[{"r":0  ,"g":  0,"b":255},{"r": 20,"g":100,"b":255},{"r": 40,"g":150,"b":255},{"r": 80,"g":180,"b":255},{"r":160,"g":220,"b":255},{"r":255,"g":255,"b":255}],
        "purple"      :[{"r":100,"g":  0,"b":255},{"r":120,"g": 20,"b":255},{"r":140,"g":100,"b":255},{"r":150,"g":150,"b":255},{"r":200,"g":200,"b":255},{"r":255,"g":255,"b":255}],
        "violet"      :[{"r":150,"g":  0,"b":255},{"r":150,"g": 50,"b":255},{"r":180,"g":100,"b":255},{"r":220,"g":140,"b":255},{"r":230,"g":180,"b":255},{"r":255,"g":255,"b":255}],
        "lavender"    :[{"r":200,"g":  0,"b":255},{"r":200,"g": 20,"b":255},{"r":200,"g": 60,"b":255},{"r":240,"g": 90,"b":255},{"r":255,"g":160,"b":255},{"r":255,"g":255,"b":255}],
        "magenta"     :[{"r":255,"g":  0,"b":255},{"r":255,"g": 60,"b":255},{"r":255,"g":100,"b":240},{"r":255,"g":150,"b":250},{"r":255,"g":180,"b":255},{"r":255,"g":255,"b":255}],
        "plum"        :[{"r":255,"g":  0,"b":200},{"r":255,"g": 20,"b":220},{"r":255,"g": 40,"b":230},{"r":255,"g":140,"b":240},{"r":255,"g":170,"b":255},{"r":255,"g":255,"b":255}],
        "rose"        :[{"r":255,"g":  0,"b":150},{"r":255,"g": 20,"b":200},{"r":255,"g": 40,"b":200},{"r":255,"g":100,"b":200},{"r":255,"g":160,"b":240},{"r":255,"g":255,"b":255}],
        "salmon"      :[{"r":255,"g":  0,"b":100},{"r":255,"g": 20,"b":120},{"r":255,"g": 80,"b":140},{"r":255,"g":100,"b":160},{"r":255,"g":140,"b":180},{"r":255,"g":255,"b":255}]
    }

    def __init__(self, x=0,y=0,z=0,t=0,c=[0,0,0],brightness=31,saturation=5):
        self.xcoord = x       #X SPACIAL COORDINATE
        self.ycoord = y       #Y SPACIAL COORDINATE
        self.zcoord = z       #Z SPACIAL COORDINATE
        self.tcoord = t       #TIME COORDINATE
        self.setColor(c,brightness,saturation)

    def writeOut(self):
        return [self.bright,self.b,self.g,self.r]

    def setColor(self, color, brightness=31, saturation=5):
        ###  color: either:
        ###         color name as string from colors table, OR
        ###         [r,g,b] list of color values
        ###  brightness: apa102 LED brightness value, between 0 and 31
        ###  saturation: color saturation, 0 as white to 5 full color
        ###
        if   (brightness > 31): brightness = 31
        elif (brightness < 0 ): brightness = 0
        self.bright = 224 + brightness
        if (type(color) == str):
            if   (saturation < 0 ): saturation = 0
            elif (saturation > 5 ): saturation = 5
            saturation  = 5  - saturation
            self.r      = self.colors[color][saturation]["r"]
            self.g      = self.colors[color][saturation]["g"]
            self.b      = self.colors[color][saturation]["b"]
        elif (type(color) == list):
            self.r = color[0]
            self.g = color[1]
            self.b = color[2]
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
